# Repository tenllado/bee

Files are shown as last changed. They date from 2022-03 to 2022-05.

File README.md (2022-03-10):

# BEE board

A simple Raspberry pi expansion board, designed with educational purposes to be
used to learn low level IO programming or used it for simple driver development.
It adds to the raspberry Pi the following circuits:

- A 10 bits ADC with 8 channels (MCP3008), that can be connected to the SPI
  gpios using 5 jumpers, it is connected to CE0.

- A 10 bit DAC (MCP4911), that can also be connected to the SPI gpios using the
  same 5 jumpers, and gets connected to CE1.

- 3 simple led circuits, and 3 switch circuits that can be connected to any gpio
  pin with some cables.

- A piezo-electric buzzer that can be connected with jumpers to the pwm pins of
  the raspberry pi.

- A shifter register connected to 7 Segment display (with dot point).

- A UART connector for the FTDI-232-R cables to connect one of the UART devices
  of the Raspberry pi to a PC.

- A standard 20 pin JTAG connector for baremetal programming and in-circuit
  debug using OpenOCD.

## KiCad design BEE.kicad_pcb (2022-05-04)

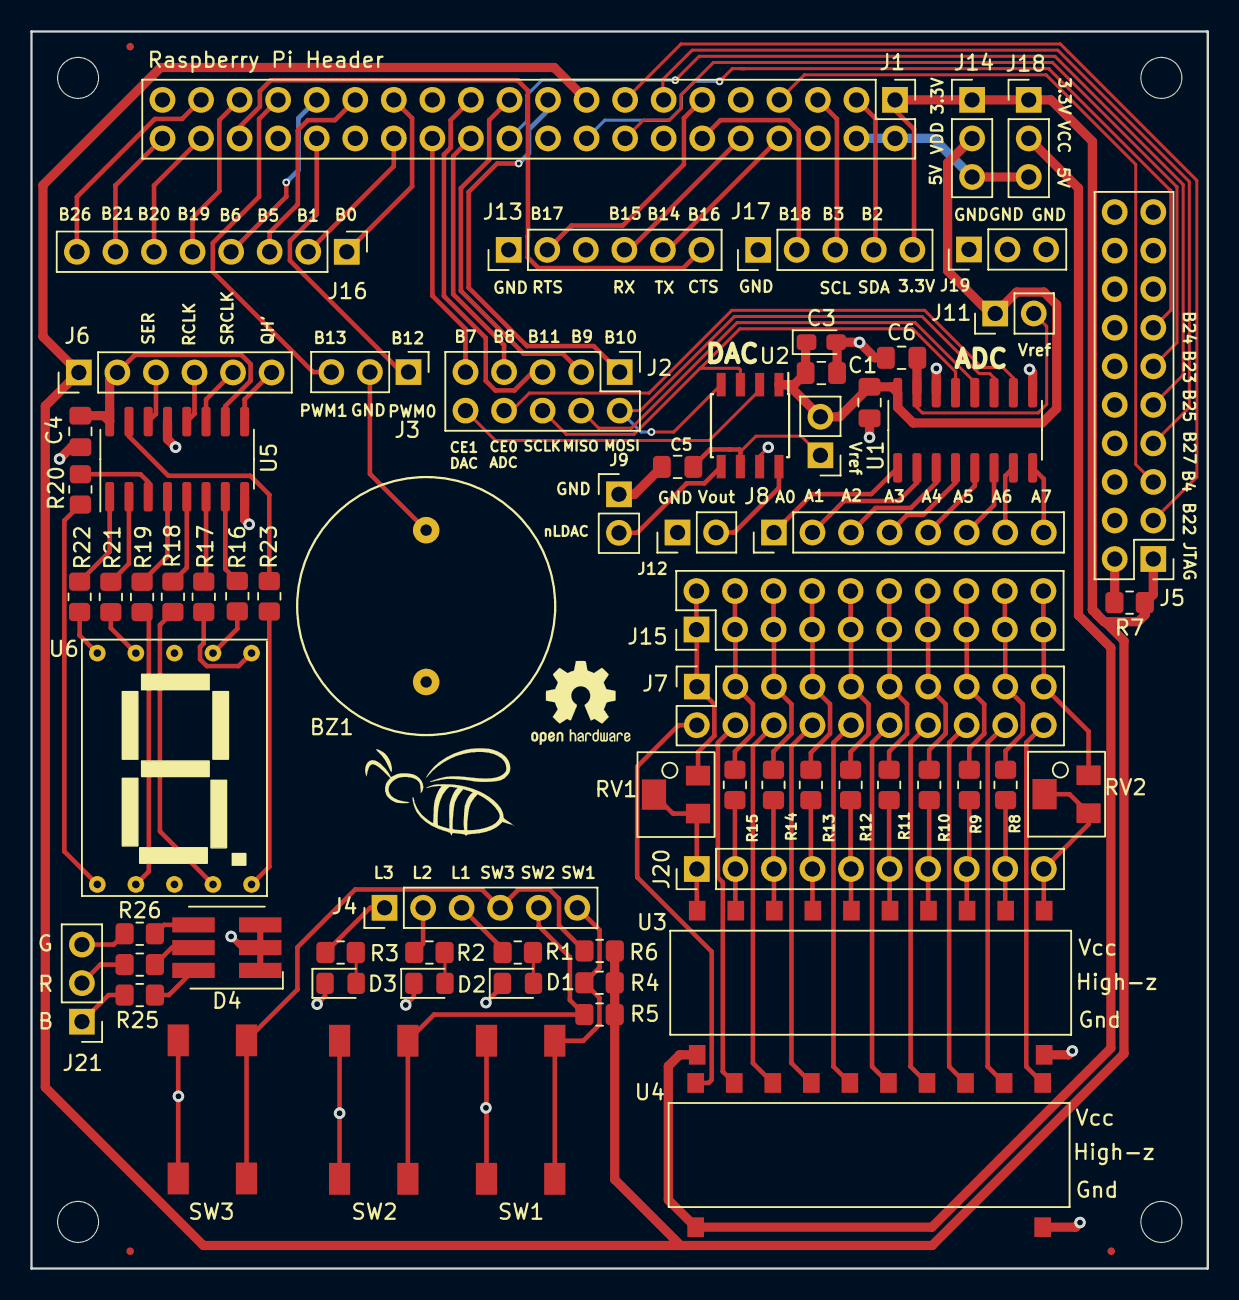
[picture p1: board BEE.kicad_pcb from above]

Board: 2 copper layers, 77.5 x 81.5 mm, 79 parts (1 on the bottom side), 118 nets.

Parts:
BZ1: /re; Buzzer
C1, C6: 1uF; C_0805_2012Metric_Pad1.18x1.45mm_HandSolder
C2, C4, C5: 0.1uF; C_0805_2012Metric_Pad1.18x1.45mm_HandSolder
C3: 10uF; CP_EIA-2012-15_AVX-P_Pad1.30x1.05mm_HandSolder
D1, D2, D3: LED; LED_0805_2012Metric_Pad1.15x1.40mm_HandSolder
D4: LED_RGB; LED_RGB_5050-6
FID1, FID2, FID3: Fiducial; Fiducial_0.5mm_Dia_1mm_Outer
H1, H2, H3, H4: MountingHole; MountingHole_2.7mm_M2.5
J1: RPI1_header; PinHeader_2x20_P2.54mm_Vertical
J2: Conn_02x05_Odd_Even; PinHeader_2x05_P2.54mm_Vertical
J3, J14, J18, J19, J21: Conn_01x03; PinHeader_1x03_P2.54mm_Vertical
J4, J6, J13: Conn_01x06; PinHeader_1x06_P2.54mm_Vertical
J5, J15: Conn_02x10_Odd_Even; PinHeader_2x10_P2.54mm_Vertical
J7: Conn_02x10_Odd_Even; PinSocket_2x10_P2.54mm_Vertical
J8, J16: Conn_01x08; PinHeader_1x08_P2.54mm_Vertical
J9, J10, J11, J12: Conn_01x02; PinHeader_1x02_P2.54mm_Vertical
J17: Conn_01x05; PinHeader_1x05_P2.54mm_Vertical
J20: Conn_01x10; PinHeader_1x10_P2.54mm_Vertical
LOGO1: Logo_Open_Hardware_Small; OSHW-Logo2_7.3x6mm_SilkScreen
LOGO2: Logo_Open_Hardware_Small; bee_logo2
LOGO3: Logo_Open_Hardware_Small; UCMLogo_169_169
R1, R2, R3, R8, R9, R16, R17, R18, R19, R20, R21, R22, R23: 220; R_0805_2012Metric_Pad1.20x1.40mm_HandSolder
R4, R5, R6, R10, R11: 10k; R_0805_2012Metric_Pad1.20x1.40mm_HandSolder
R7: 0; R_0805_2012Metric_Pad1.20x1.40mm_HandSolder
R12, R13: 15k; R_0805_2012Metric_Pad1.20x1.40mm_HandSolder
R14, R15: 47k; R_0805_2012Metric_Pad1.20x1.40mm_HandSolder
R24: 280; R_0805_2012Metric_Pad1.20x1.40mm_HandSolder
R25, R26: 100; R_0805_2012Metric_Pad1.20x1.40mm_HandSolder
RV1, RV2: 100k; POT_PVG5A
SW1, SW2, SW3: SW_Push; PushButton
U1: MCP3008; SOIC-16_3.9x9.9mm_P1.27mm
U2: MCP4911; SOIC-8_3.9x4.9mm_P1.27mm
U3, U4: Dip_10xsp3t; dip_10xsp3t
U5: 74AHC595; SOIC-16_3.9x9.9mm_P1.27mm
U6: Display_7Segments; 7segments

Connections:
+3V3: J1.1 (+3.3V), J1.17 (+3.3V), J5.1, J6.1, J14.1, J17.5, J18.1, R4.1, R5.1, R6.1, R7.1
+5V: J1.2 (+5V), J1.4 (+5V), J14.3, J18.3
/BCM0: J1.27 (BCM0), J16.1
/BCM1: J1.28 (BCM1), J16.2
/BCM2_SDA: J1.3 (BCM2_SDA), J17.4
/BCM3_SCL: J1.5 (BCM3_SCL), J17.3
/BCM4_TDI: J1.7 (BCM4_TDI), J5.5
/BCM5: J1.29 (BCM5), J16.3
/BCM6: J1.31 (BCM6), J16.4
/BCM7_CE1: J1.26 (BCM7_CE1), J2.9
/BCM8_CE0: J1.24 (BCM8_CE0), J2.7
/BCM9_MISO: J1.21 (BCM9_MISO), J2.3
/BCM10_MOSI: J1.19 (BCM10_MOSI), J2.1
/BCM11_SCLK: J1.23 (BCM11_SCLK), J2.5
/BCM12_PWM0: J1.32 (BCM12), J3.1
/BCM13_PWM1: J1.33 (BCM13), J3.3
/BCM14_TX: J1.8 (BCM14_TX), J13.5
/BCM15_RX: J1.10 (BCM15_RX), J13.4
/BCM16_CTS: J1.36 (BCM16), J13.6
/BCM17_RTS: J1.11 (BCM17), J13.2
/BCM18: J1.12 (BCM18_PWM), J17.2
/BCM19: J1.35 (BCM19), J16.5
/BCM20: J1.38 (BCM20), J16.6
/BCM21: J1.40 (BCM21), J16.7
/BCM22_TRST: J1.15 (BCM22_TRST), J5.3
/BCM23_RTCK: J1.16 (BCM23), J5.11
/BCM24_TDO: J1.18 (BCM24_TDO), J5.13
/BCM25_TCK: J1.22 (BCM25_TCK), J5.9
/BCM26: J1.37 (BCM26), J16.8
/BCM27_TMS: J1.13 (BCM27_TMS), J5.7
/CE_ADC: J2.8, U1.10 (~CS/SHDN)
/CE_DAC: J2.10, U2.2 (~CS)
/L1: J4.3, R1.1
/L2: J4.2, R2.1
/L3: J4.1, R3.1
/MISO: J2.4, U1.12 (Dout)
/MOSI: J2.2, U1.11 (Din), U2.4 (SDI)
/QH': J6.6, U5.9 (QH')
/RCLK: J6.4, U5.12 (RCLK)
/SCLK: J2.6, U1.13 (CLK), U2.3 (SCK)
/SER: J6.3, U5.14 (SER)
/SRCLK: J6.5, U5.11 (SRCLK)
/SW1: J4.6, R4.2, SW1.1
/SW2: J4.5, R5.2, SW2.1
/SW3: J4.4, R6.2, SW3.1
GND: BZ1.2 (+), C1.2, C2.2, C3.2, C4.2, C5.1, C6.1, D1.1 (K), D2.1 (K), D3.1 (K), D4.1 (RK), D4.3 (GK), D4.5 (BK), J1.6 (Gnd), J1.9 (Gnd), J1.14 (Gnd), J1.20 (Gnd), J1.25 (Gnd), J1.30 (Gnd), J1.34 (Gnd), J1.39 (Gnd), J5.4, J5.6, J5.8, J5.10, J5.12, J5.14, J5.16, J5.18, J5.20, J9.1, J12.1, J13.1, J17.1, J19.1, J19.2, J19.3, SW1.2, SW2.2, SW3.2, U1.9 (DGND), U1.14 (AGND), U2.7 (Vss), U3.11 (-), U4.11 (-), U5.8 (GND), U5.13 (~OE), U6.3 (CA), U6.8 (CA)
unnamed: BZ1.1 (-), J3.2
unnamed: C5.2, J10.1, U2.6 (Vref)
unnamed: C6.2, J11.2, U1.15 (Vref)
unnamed: D1.2 (A), R1.2
unnamed: D2.2 (A), R2.2
unnamed: D3.2 (A), R3.2
unnamed: D4.2 (RA), R25.2
unnamed: D4.4 (GA), R24.2
unnamed: D4.6 (BA), R26.2
unnamed: J5.2, R7.2
unnamed: J7.2, U4.1
unnamed: J7.4, U4.2
unnamed: J7.6, U4.3
unnamed: J7.8, U4.4
unnamed: J7.10, U4.5
unnamed: J7.12, U4.6
unnamed: J7.14, U4.7
unnamed: J7.16, U4.8
unnamed: J7.18, U4.9
unnamed: J7.20, U4.10
unnamed: J8.1, U1.1 (CH0)
unnamed: J8.2, U1.2 (CH1)
unnamed: J8.3, U1.3 (CH2)
unnamed: J8.4, U1.4 (CH3)
unnamed: J8.5, U1.5 (CH4)
unnamed: J8.6, U1.6 (CH5)
unnamed: J8.7, U1.7 (CH6)
unnamed: J8.8, U1.8 (CH7)
unnamed: J9.2, U2.5 (~LDAC)
unnamed: J12.2, U2.8 (Vout)
unnamed: J7.1, J15.1, J15.2, RV1.3
unnamed: J7.3, J15.3, J15.4, R15.2
unnamed: J7.5, J15.5, J15.6, R14.2
unnamed: J7.7, J15.7, J15.8, R13.2
unnamed: J7.9, J15.9, J15.10, R12.1
unnamed: J7.11, J15.11, J15.12, R11.2
unnamed: J7.13, J15.13, J15.14, R10.1
unnamed: J7.15, J15.15, J15.16, R9.1
unnamed: J7.17, J15.17, J15.18, R8.1
unnamed: J7.19, J15.19, J15.20, RV2.3
unnamed: J20.1, RV1.1, RV1.2, U3.1
unnamed: J20.2, R15.1, U3.2
unnamed: J20.3, R14.1, U3.3
unnamed: J20.4, R13.1, U3.4
unnamed: J20.5, R12.2, U3.5
unnamed: J20.6, R11.1, U3.6
unnamed: J20.7, R10.2, U3.7
unnamed: J20.8, R9.2, U3.8
unnamed: J20.9, R8.2, U3.9
unnamed: J20.10, RV2.1, RV2.2, U3.10
unnamed: J21.1, R25.1
unnamed: J21.2, R24.1
unnamed: J21.3, R26.1
unnamed: R16.1, U6.7 (A)
unnamed: R16.2, U5.7 (QH)
unnamed: R17.1, U6.6 (B)
unnamed: R17.2, U5.6 (QG)
unnamed: R18.1, U6.4 (C)
unnamed: R18.2, U5.5 (QF)
unnamed: R19.1, U6.2 (D)
unnamed: R19.2, U5.4 (QE)
unnamed: R20.1, U6.1 (E)
unnamed: R20.2, U5.3 (QD)
unnamed: R21.1, U6.9 (F)
unnamed: R21.2, U5.2 (QC)
unnamed: R22.1, U6.10 (G)
unnamed: R22.2, U5.1 (QB)
unnamed: R23.1, U6.5 (DP)
unnamed: R23.2, U5.15 (QA)
VCC: J18.2, U3.12 (+), U4.12 (+)
VD: C4.1, J6.2, U5.10 (~SRCLR), U5.16 (VCC)
VDD: C1.1, C2.1, C3.1, J10.2, J11.1, J14.2, U1.16 (Vdd), U2.1 (Vdd)

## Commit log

2019-10-04 no signal reorder
    [BEE.kicad_pcb, BEE.sch]
2019-10-04 small change
    [BEE.kicad_pcb]
2019-10-05 wip: some traces added
    [BEE.kicad_pcb]
2019-10-06 wip:pcb routed, raspi header can be moved right
    [BEE.kicad_pcb, BEE.sch]
2019-10-06 wip: routed, raspi header can be moved right
    [BEE.kicad_pcb]
2019-10-07 wip some traces re-routed
    [BEE.kicad_pcb, BEE.sch]
2019-10-07 wip: with mounting holes, board a little bit bigger
    [BEE.kicad_pcb, BEE.sch]
2019-10-08 uart connector with jumpers to select crossed or direct connection. rerouted and labeled
    [BEE.kicad_pcb, BEE.sch]
2019-10-08 additional via for led circuits
    [BEE.kicad_pcb]
2019-10-09 reposition, reroute, removed cross connector for UART. Labeled
    [BEE.kicad_pcb, BEE.sch]
2019-10-09 Fiducials and Logos
    [BEE.kicad_pcb, BEE.sch]
2019-10-09 UCM logo and github repo url
    [BEE.kicad_pcb, BEE.sch]
2019-10-10 some traces redone for better return path on ground plane. Reposition of fiducials.
    [BEE-B.Cu.gbr, BEE-B.Mask.gbr, BEE-B.Paste.gbr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]
2019-10-11 return current loops reduced
    [BEE.kicad_pcb]
2019-10-13 self made logo
    [BEE.kicad_pcb, BEE.sch]
2019-10-13 github url of the project in the schematic
    [BEE.sch]
2019-10-15 revision of fab layer. Ref designator in fab layer. bom
    [BEE.kicad_pcb, BEE.sch, BEE_bom.csv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]
2019-10-16 mounting holes 2.7mm
    [BEE.kicad_pcb, BEE.sch]
2019-10-16 gerbers and fill zones update
    [BEE-B.Cu.gbr, BEE-B.Mask.gbr, BEE-B.Paste.gbr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]
2019-10-18 Gerbers update
    [BEE-B.Cu.gbr, BEE-B.Mask.gbr, BEE-B.Paste.gbr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]
2019-11-13 changing some minor things after first prototype test
    [BEE-B.Cu.gbr, BEE-B.Mask.gbr, BEE-B.Paste.gbr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]
2020-01-17 wip Resistors and new pin connectors
    [BEE.kicad_pcb, BEE.sch]
2020-01-18 separate vcc connector moved down
    [BEE.kicad_pcb]
2020-01-19 vcc down with double socket for external sensors
    [BEE.kicad_pcb, BEE.sch]
2020-01-19 new position and routes for resistors for sensors
    [BEE.kicad_pcb]
2020-01-19 replace and reroute: jtag signals on the sides
    [BEE.kicad_pcb, BEE.sch]
2020-01-19 Remove connector with gnd, +3.3v and +5V, and reroute
    [BEE.kicad_pcb, BEE.sch]
2020-01-19 some extra labels in silk screen
    [BEE.kicad_pcb]
2020-01-19 small obsesive changes
    [BEE.kicad_pcb]
2020-01-20 minor mod, track simplified
    [BEE.kicad_pcb]
2020-01-20 jtag connector rotated, jtag signals on the right
    [BEE.kicad_pcb]
2020-01-20 some tracks redone, not sure if it is any better
    [BEE.kicad_pcb]
2020-01-20 minor placement and labeling modifications
    [BEE.kicad_pcb]
2020-03-15 Gerbers for new revision
    [BEE-B.Cu.gbr, BEE-B.Mask.gbr, BEE-B.Paste.gbr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]
2020-10-19 component changes
    [BEE.sch, BEE_bom.csv, BEE_bom.xlsx]
2020-10-19 BOM files
    [BEE_bom.csv, BEE_bom.xlsx]
2022-03-08 last changes
    [BEE.kicad_pcb]
2022-03-09 first version with display and dip switches
    [BEE.kicad_pcb, BEE.sch]
2022-03-09 test of alternative layout
    [BEE.kicad_pcb]
2022-03-10 vertical block for display driver
    [BEE.kicad_pcb]
2022-03-10 Bypass cap for Shifter, DAC cap symbol fix, DAC out pin headers reorganization, labels and fab layer cleanup.
    [BEE.kicad_pcb, BEE.sch]
2022-03-11 independent polarization network
    [BEE.kicad_pcb, BEE.sch]
2022-03-11 3D models for dip switches
    [BEE.kicad_pcb]
2022-03-11 Extra pin headers in polarization network and 3d models
    [BEE.kicad_pcb, BEE.sch]
2022-03-11 Bit endianness change in display shifter, and some other minor changes to that driver
    [BEE.kicad_pcb, BEE.sch]
2022-03-11 fab layer cleanup
    [BEE.kicad_pcb]
2022-03-11 ucm logo and project moved
    [BEE.kicad_pcb]
2022-03-13 RGB Led and J17 adaptation to pimoroni breakouts
    [BEE.kicad_pcb, BEE.sch]
2022-03-14 small rerouting of rgb led module
    [BEE.kicad_pcb, BEE.sch]
2022-03-15 Migration to kicad 6.0
    [BEE.kicad_pcb, BEE.kicad_sch]
2022-03-23 changed RGB led by a bigger 5050 one
    [BEE.kicad_pcb, BEE.kicad_sch]
2022-03-23 D4 pin numbering adjusted on schematic and footprint, according to datasheet
    [BEE.kicad_pcb, BEE.kicad_sch]
2022-03-24 labels for RGB led
    [BEE.kicad_pcb]
2022-04-21 BEE 2.0 final touches
    [BEE.kicad_pcb, BEE_bom.csv, BEE_bom.xlsx]
2022-04-21 remove Gerbers files from repo
    [BEE-B.Cu.gbr, BEE-B.Mask.gbr, BEE-B.Paste.gbr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]
2022-04-25 renombrado de Manufacturer PN a MPN. borrado ficheros versión anterior
    [BEE.kicad_pcb, BEE.kicad_sch, BEE.sch]
2022-05-04 changes for fabrication
    [BEE.kicad_pcb, BEE.kicad_sch]
